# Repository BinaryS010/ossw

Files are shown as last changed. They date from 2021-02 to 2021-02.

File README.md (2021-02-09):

# Open SCART SWitch (OSSW)

## Overview

The **Open SCART Switch** (OSSW) is an RGB video and audio SCART switch designed to connect up to **8** RGB capable video game consoles with compatible display devices or scalers such as the **Open Source Scan Converter (OSSC).**

It was designed for use with properly constructed **RGB SCART** cables which correctly attenuate video and sync signals to levels safe for use with consumer grade televisions and the OSSC.

## Motivation

I designed this device to scratch a few itches, but mostly because there are currently no open source SCART switch designs within the retro gaming community.

It would have been cheaper to buy an existing solution, of which there are several very good ones, but I've learnt a lot throughout this project.

## Features

Currently the OSSW has the following features:

 * **8** SCART **inputs**, with **2** SCART **outputs**. Supports simultaneous output (**untested**).
 * Integrated **video amplifier** and switchable **sync stripper.**
 * Support for **Composite sync (CSYNC)**, **Sync-over-composite** or **Sync-on-Luma** on **SCART pin 20.**
 * Backlit LCD character **display** with menu driven interface.
 * Infrared **remote** and **5 button** control interface support.
 * Line-level **stereo audio** output via RCA jacks.
 * Built in 64Kb **EEPROM** to save and load configuration data.
 * Externally powered by **7.5V DC** supply. **2.5mm** barrel jack, centre positive.
 * Power **input polarity** and **over-voltage protection**, with onboard 1A fuse.
 * **SD Card** interface. (**unused/untested**, see future features).
 * Simple **expansion** interface for future feature support (**untested**).
 * Transient voltage **protection** for SCART Input and Outputs (**untested**).

### Limitations

The following are known limitations with the OSSW:

 * **Euro SCART** only. Currently NO support for **JP-21 SCART** standard.
 * Currently, **manual** switching only (see future features below).
 * No **audio amplification** is performed by the OSSW. Audio is currently split between the two SCART outputs and the RCA stereo jacks. A decrease in audio volume may be noticeable when using multiple outputs simultaneously (see future features below).
 * Input and output SCART ports can tolerate a maximum of **5V.** Use properly constructed RGB SCART cables to ensure no signal line (particularly, **SCART pin 8**) carries no more than **5V**.
 * Fimware only upgradeable using compatible programmer, such as an Atmel ICE (see future features).
 * Infrared remote control decoding is currently limited to **NEC protocol** only. Remote specific codes are hard-coded in the firmware.

### Future Features

The following features are planned for the OSSW:

 * Audio amplification.
 * Sync detection and automatic switching funtionality.
 * SD card based firmware upgrades and custom profile loading and saving.
 * Infrared remote control training and additional protocol decoding support.

### Warnings

Currently the device should only be used with **75 ohm** attenuated sync signals. Using the OSSW with **TTL** level sync signals will likely damage upstream devices such as the OSSC.

## Hardware

OSSW hardware overview and build instructions are located in the [HARDWARE](./HARDWARE.md) readme.

## Firmware

OSSW firmware build, programming and debugging instructions are located in the [FIRMWARE](./FIRMWARE.md) readme.

## Usage

OSSW usage instructions are located in the [USAGE](./USAGE.md) readme.

## Revision history

Please see the [CHANGELOG](./CHANGELOG)

## Disclaimer

This is a **DIY hobby** project currently in an early prototype stage. 

I am **not** a trained electrical engineer and although this device seems to work well with my equipment it may not work so well with other setups.

I **do not** intend to sell kits or completed devices. Design files are released to the community in the hope that the design may be improved upon should people wish to contribute. 

I **may** sell surplus PCBs at around cost price (+shipping) but **ONLY** if I have them available.

I offer **NO WARRANTY** of any kind and assume **NO RESPONSIBILITY** for potential damage or loss caused by this device. **Use the information in the repository at your own risk.**

I also offer **NO GUARANTEE** of support if you attempt to build and operate one of these devices. This is a hobby project and not a business. I'm open to contributions and suggestions on current or future features but it's unlikely I'll have time to answer direct queries.

## Donations

Donations are certainly not expected or required. However, if you would like to contribute a small donation towards future revisions of this project then please use one of the methods below:

 * Paypal: **ossw AT binarysolo.co.uk** (replace AT with @).
 * Bitcoin: **36CN15aT6YL5B6MN5kqg4JD5AhEYchCwxG**

Any and all donations are greatly appreciated.

## License

This project is licensed under the GNU General Public License, version 3 (GPLv3).

## Copyright

The **Open Scart Switch (OSSW)** project is Copyright(c) 2019-2021 Binary Solo.

Elements of the OSSW project that are derived from other works are credited within the relevant source files. Those works are copyright of their respective owners as indicated in the original copyright notice.

## Contact

The OSSW developer can be contacted via email as **ossw AT binarysolo.co.uk** (replace the AT with @).

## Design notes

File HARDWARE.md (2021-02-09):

# Hardware

This document is the main reference for the hardware components of the **OSSW** project intended to enable DIY build and assembly of the device.

The hardware is currently considered to be in an **ALPHA** release state. It may not be entirely safe for use across all setups and is subject to change. 

Certain elements of the hardware are sub-optimal, so please respect the fact that this is still considered a prototype design.

## Overview

The OSSW hardware forms the basis of an **8 input** and **2 output** RGB SCART switch with the following main components:

 * Dual PCB design consisting of:
    * Main board, 4 layers (~400mm x 130mm).
    * LCD display carrier board, 2 layers (~75mm x 28mm).
 * Laser cut acrylic case (3mm thickness). 

## Main components

The following components implement the major functionality of the OSSW:

 * Atmel/Microchip **ATSAMD21J18A** TQFP-64, microcontroller providing input/output and user interface control.
 * Information output via Midas **MCCOG22005A6W** 20x2 I2C LCD character display.
 * Bus switching via **SN74CBT3244** Octal FET bus switch ICs.
 * Video amplification via **THS7374** 4-channel SD video amplifier IC, including user selectable LPF filter.
 * Selectable video sync-stripping via **LM1881** sync separator IC.
 * Storage facilitated by **24LC64** 64Kb I2C EEPROM IC.
 * Infrared remote control via **TSOP 38238** 38kHz IR receiver/decoder module.
 * Manual control using 5 tactile buttons with hardware debouncing via **SN74HC14** Hex schmitt-trigger IC.
 * Serial wire debug support via 10 pin (2x5), 1.27mm pitch header.
 * SD-Card connector for future feature support and end-user firmware upgrade.
 * Bus status LED indicators (Green).

### Power supply

 * Power is delivered using a **7.5V DC (centre positive)** supply, with a current rating of **1A**.
 * The main power connector is a **FC681465P** 2.5mm barrel jack.
 * Power is regulated as follows:
    * 5V: **NCP1117ST503G**, 5V/1A LDO, powering bus switches and video amplifier.
    * 3V: **NCP1117ST333G**, 5V/1A LDO, powering ATSAMD MCU and additional low-voltage components.
 * Power status LED indicators (Red). 

## ATSAMD pinout

The following table describe the assigned pin functions of the OSSW's ATSAMD21J18A microcontroller.

|Port|Pin|Usage|Description|
|:---|---|:---|:---|
|PA00|1|XIN32|32.768kHz crystal|
|PA01|2|XOUT32|32.768kHz crystal|
|PA02|3|EXT_CTRL1|EXT control interface 1|
|PA03|4|EXT_CTRL2|EXT control interface 2|
|PA04|13|BUS_EN5|Bus Switch 5 enable|
|PA05|14|BUS_EN6|Bus Switch 6 enable|
|PA06|15|BUS_EN7|Bus Switch 7 enable|
|PA07|16|BUS_EN8|Bus Switch 8 enable|
|PA08|17|-|-|
|PA09|18|-|-|
|PA10|19|-|-|
|PA11|20|-|-|
|PA12|29|-|-|
|PA13|30|-|-|
|PA14|31|BYPASS|THS7374 LPF bypass enable/disable|
|PA15|32|SYNC_SPLIT|LM1881 Sync-stripper enable/disable|
|PA16|35|SERCOM1 PAD0|I2C SDA|
|PA17|36|SERCOM1 PAD1|I2C SCL|
|PA18|37|BTN_DOWN|Button Down|
|PA19|38|BTN_UP|Button Up|
|PA20|41|BTN_ACTION|Button Action|
|PA21|42|BTN_LEFT|Button Left|
|PA22|43|BTN_RIGHT|Button Right|
|PA23|44|-|-|
|PA24|45|-|-|
|PA25|46|-|-|
|PA27|51|IR_RECV|IR Receiver|
|PA28|53|-|-|
|PA30|57|SWCLK|-|
|PA31|58|SWDIO|-|
|PB00|61|SD_CS|SPI/SD-Card Chip Select|
|PB01|62|SD_MISO|SPI/SD-Card Master-In, Slave-Out|
|PB02|63|-|-|
|PB03|64|-|-|
|PB04|5|EXT_CTRL3|EXT control interface 3|
|PB05|6|EXT_CTRL4|EXT control interface 4|
|PB06|9|BUS_EN1|Bus Switch 1 enable|
|PB07|10|BUS_EN2|Bus Switch 2 enable|
|PB08|11|BUS_EN3|Bus Switch 3 enable|
|PB09|12|BUS_EN4|Bus Switch 4 enable|
|PB10|23|-|-|
|PB11|24|-|-|
|PB12|25|-|-|
|PB13|26|-|-|
|PB14|27|-|-|
|PB15|28|-|-|
|PB16|39|-|-|
|PB17|40|-|-|
|PB22|49|-|-|
|PB23|50|LCD_BL|LCD LED Backlight enable/disable|
|PB30|59|SD_MOSI|SPI/SD-Card Master-Out, Slave-In|
|PB31|60|SD_SCK|SPI/SD-Card Clock|
|RESET|52|RESET|Button Reset|

## Manufacture

Building the OSSW device from scratch is a relatively difficult task due to the high part count and the size of some of the components used. 

However, it should be achievable by most experienced electronics hobbyists comfortable with soldering at least **0402/0603 SMD** components and **0.5mm pin pitch** surface mount IC packages. 

Hot air rework stations and/or reflow ovens will certainly help although are not strictly required. The prototype unit was built using a **temperature controlled** KSGER T12 soldering iron and a variety of tips suitable for general purpose and SMD work.

### PCBs

The PCBs for DIY OSSW builds can be ordered from any low cost PCB house and have few special requirements. Prototype units were manufactured by JLCPCB and are of acceptable quality.

Due to the size of the main board and the 4 layer design, manufacture and shipping costs are slightly higher. For reference, 5 copies of both boards for the prototype cost around **£80** total (including import taxes and shipping).

GERBER files for the two PCBs can be found in the *GERBER/* folder for the relevant board and version under the *pcb/* folder in the root of the repository.

#### Design files

The OSSW PCB hardware was designed using the **KiCAD** EDA Suite, version **5.1.6-c6e7f7d~87~ubuntu18.04.1, release build** at the time of writing. Full design files are available in the *pcb/* folder within the source repository.

There is currently no intention to port the design to other EDA suites.

#### Ordering

 * Main OSSW board:
    * Thickness: **2.0mm** (1.6mm is really too thin for a board of this size).
    * Surface finish: No special requirement, HASL is fine.
    * Solder mask: Your choice, **Black** looks good but is **HARDER** to work and clean after soldering.

 * LCD carrier board:
    * Thickness: **1.6mm.**
    * Surface finish and solder mask: No special requirements.

#### Bill of Materials

The BOMs for each OSSW PCB can be found in the *BOM/* folder under the relevant board revision within the *pcb/* folder in the root of the source repository. 

As the BOM will likely change across board revisions it is best to place it alongside the relevant design files.

Generally, all schematic elements within the design contain the manufacturer part number and relevant datasheet links. 

Large online electronics distributors (Mouser/Digikey/Farnell etc) carry most of the BOM items. The exception here is the SCART connectors which are either salvaged or available from online auction sites such as Ebay.

The BOM for the two PCBs is generated by the **InteractiveHtmlBom** plugin for KiCAD.

### Assembly

Component placement should be self-explanatory from the included design files for each board and revision. Use of the **InteractiveHtmlBOM** plugin for KiCAD can be useful during soldering.

Based on hand assembly of the prototype unit, the following tips and warnings may prove useful.

#### LCD carrier board

When assembling the LCD daughter board for use with the OSSW, please ensure you **omit** the parts labelled **R1** and **R2.** These footprints are used as pull-up resistors for the **I2C** bus. Since the main OSSW PCB contains these parts they are **not** required on the LCD display carrier board.

**Note:** Failure to adhere to this warning will cause communication errors on the I2C bus and the OSSW is unlikely to boot correctly.

#### Tips

 * Flux, preferably the liquid no-clean variety, is required to ensure surface mount components are soldered easily and correctly.
 * Residual flux from soldering should be cleaned using >90% Isopropyl Alcohol (IPA) and a soft anti-static brush.
 * It is advised to start by soldering the ATSAMD microcontroller and verifying there are no shorted pins before soldering the rest of the components.
 * For the remainder of the components, start with the lowest profile components and continue in that fashion for the rest of the build.
 * Solder all connectors and buttons last. It is advisable to test the unit before soldering ALL the SCART connectors onto the board.
 * Once the unit is verified to be working, the LCD daughter board can be permanently fixed in place using the solder pads on both sides of the main board.
 * Use a **multimeter** to verify connectivty, particularly with the power circuitry, **BEFORE** powering on a newly assembled unit.

#### Warnings

 * **DO NOT** use hot air to solder, or nearby to, **ANY** plastic containing components on the board. Doing so will likely melt the plastic and damage/destroy the component. Kapton tape can be used to carefully isolate already soldered plastic components if rework is required. 
 * Ensure **all** safety precautions are taken when soldering components. Solder fumes and flux are generally considered to be **toxic** substances. 
 * If using leaded solder, this device will not be RoHS compliant. Prototype units were assembled using leaded solder.

### Case

A **preliminary** design for a two part case, consisting of a top and bottom plate, is included within this repository. **As I have not made one yet, I cannot guarantee it is correct.**

It is expected that the case can be laser cut or machined from 3mm acrylic using a variety of online merchants, or at home if you have the equipment.

It may be possible to 3D print the case design, subject to access to a printer with a build volume of ~400mm x 150mm. This is likely to be of a lower quality than the acrylic option.

### Design files

The OSSW case was designed using **Inkscape**, version **0.92.3 (2405546, 2018-03-11)** at the time of writing. Files are available in the *case/* folder within the source repository for the relevant main board revision.

### Additional components

As well as the electronic components, you will also need the following components to completely assemble the OSSW:

 * Brass/Steel PCB standoffs, 12mm (**6** x Male/Female, **26** x Female/Female).
 * M3 x 6mm screws (**26**).

### Future Work

There are plenty of features that *could* be implemented into the hardware, subject to demand. These features are already outlined in the main [README](./README.md) file for this project.

I am aware that the current BOM is rather costly and could do with some consolidation.

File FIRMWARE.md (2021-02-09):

# Firmware

This document is the main reference for the firmware components of the OSSW project intended to enable development, debugging and programming of the Atmel ATSAMD microcontroller.

The software is currently considered to be in an **ALPHA** release state. Generally, all of the existing features have been tested and appear stable under a reasonable amount of usage to date.

## Development environment

The OSSW firmware has been developed using almost exclusively open source environments and toolchains. The primary development environment is **Ubuntu 18.04.4 LTS x86_64.** 

It should be relatively easy to use other Linux based development environments.

### Prequisite packages

In order to build the firmware and program the OSSW, the development environment must first be configured.

### Build tools

Firstly, install the required build packages using the package manager of your preferred distribution.

```
sudo apt-get install build-essential openocd telnet
```

### ARM GNU toolchain

Developing for the ATSAMD microcontroller requires a cross toolchain for the ARM Cortex M0+ architecture. 

Whilst you are free to build or use one you may already have, I chose to use the **official** GNU ARM Embedded toolchain which can be downloaded from this [link](https://developer.arm.com/tools-and-software/open-source-software/developer-tools/gnu-toolchain/gnu-rm/downloads)

The version used during development of the OSSW was: [Version 7-2017-Q4-major](https://developer.arm.com/-/media/Files/downloads/gnu-rm/7-2017q4/gcc-arm-none-eabi-7-2017-q4-major-linux.tar.bz2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,64-bit,,Linux,7-2017-q4-major).

Later versions have **NOT** been tested, but I expect they'll work just fine.

#### Download and extract toolchain

Download the toolchain and extract it to a location of your choosing. In my case I use `~/toolchains` as follows:

```
mkdir ~/toolchains
cd ~/toolchains

wget "https://developer.arm.com/-/media/Files/downloads/gnu-rm/7-2017q4/gcc-arm-none-eabi-7-2017-q4-major-linux.tar.bz2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,64-bit,,Linux,7-2017-q4-major" -O gcc-arm-none-eabi-7-2017-q4-major.tar.bz2

tar xjvf gcc-arm-none-eabi-7-2017-q4-major.tar.bz2
ln -s gcc-arm-none-eabi-7-2017-q4-major/install-native arm-none-eabi
```

#### Configure PATH environment variable

Once extracted, you now need to add the toolchain to your `PATH` environment variable for the makefile to pick it up and cross compile the firmware. In order to do this, you could add the following lines to your `~/.profile` as follows:

```
PATH="$PATH:$HOME/toolchain/arm-none-eabi/bin/"
export PATH
```

Once this is complete, `source` your profile to pick up the changes and add the toolchain to your path.

```
. ~/.profile
```

Toolchain configuration is now complete.

### Atmel/Microchip ASF

In order to aid development, and possibly portability to alternative ATSAMD devices, the OSSW firmware was developed against the Atmel/Mircochip ASF development kit. 

**Note:** The only portions of the ASF that are really used are the ATSAMD starup code and memory mapped register definitions and helper macros. The OSSW firmware does **NOT** use the full Hardware Abstraction Layer (HAL) library features provided by the ASF so the included code is only very minimal, probably around 1KB.

Follow the steps below to download and configure the ASF:

#### Download ASF

Download the standalone ASF archive from [here](https://www.microchip.com/en-us/development-tools-tools-and-software/libraries-code-examples-and-more/advanced-software-framework-for-sam-devices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). 

The version used to develop the OSSW firmware was **3.47.0.96** although the current version available for download is **3.49.1.105** at the time of writing. It is a **~0.5Gb** download.

#### Extract ASF

Firstly, extract the ASF to a location **outside** of the OSSW source repository. In this example *~/share* is used.

```
cd ~
mkdir share
cd share
unzip ~/Downloads/asf-standalone-archive-<version>.zip
ln -s xdk-ask-<version> xdk-asf
```

#### Link to ASF

Now that the ASF is installed to a known location, the *Makefile* needs to be able to locate the relevant files needed to build the firmware.

The creation of an additional directory is required in the root of the OSSW source respository to point to the external files. In this example, an *ext/* directory is created.

```
cd <ossw_repository_directory>
mkdir ext
cd ext
```

Now create the following symlinks to the various ASF components required, replacing `username` with your own:

```
ln -s /home/<username>/share/xdk-asf/thirdparty/CMSIS/Include/ cmsis
ln -s /home/<username>/share/xdk-asf/thirdparty/CMSIS/Include/ include
ln -s /home/<username>/share/xdk-asf/sam0/utils/linker_scripts/samd21/gcc/samd21j18a_flash.ld samd21j18a_flash.ld
ln -s /home/<username>/share/xdk-asf/sam0/utils/cmsis/samd21/source/gcc/startup_samd21.c startup_samd21.c
ln -s /home/<username>/share/xdk-asf/sam0/utils/cmsis/samd21/source/system_samd21.c system_samd21.c
ln -s /home/<username>/share/xdk-asf/sam0/utils/cmsis/samd21/source/system_samd21.h system_samd21.h
```

Setup of the development environment is now complete.

#### Additional reference

A good reference for bare-metal ARM programming can be found on the MickMake YouTube channel [here](https://youtu.be/xy62eC6bd44). The instructions in this guide are based on this video.

### Additional tools

#### Programmer (required)

This document assumes you have an Atmel ICE or other suitable programmer available and  connected to the onboard *Serial Wire Debug* port located on the main OSSW board. For now, this is the **ONLY** method available for programming and/or debugging the Atmel ATSAMD microcontroller on the OSSW.

If using an Atmel ICE, the **SAM** debug port should be used as opposed to the **AVR** port on the programmer.

#### Logic Analyser (optional)

A logic analyser is often useful for both debugging and verifying commnication signals during development, particularly the protocols involved in I2C, SPI and Infrared communicatons. 

It is however optional, and not required to build and program an OSSW device.

## Configure programmer

The OSSW repository contains an **openocd** configuration file in the *cfg/* directory in the root of the source repository.

In order to configure your programmer correctly you need update the configuration file with the appropriate USB VID, PID and serial number of your particular programmer.

These values can be obtained by the following commands with the programmer connected and powered on:

```
lsusb -v | less 
```

Search the output for the following lines:

```
idVendor           0x03eb Atmel Corp.
idProduct          0x2141 ICE debugger
bcdDevice            1.01
iManufacturer           1 Atmel Corp.
iProduct                2 Atmel-ICE CMSIS-DAP
iSerial                 3 J47201015054
```

The relevant values from *your* output fields **idVendor** (in this case 0x03eb), **idProduct** (0x2141) and **idSerial** (J47201015054) should be entered into the *cfg/openocd.cfg* file before attempting to program or debug the firmware.

## Debugging the firmware

Being able to debug the Atmel ATSAMD21J18A microcontroller is essential during development and testing. The included *Makefile* has a few targets to enable this. 

Firstly, to ensure relevant debugging information is present within the firmware binary, a **debug** target is also provided within the *Makefile*.

Secondly, the **openocd**  target connects to the ATSAMD and places it under the control of the openocd debugger. An openocd config file suitable for the ATSAMD21J18A target is present within the *cfg/* directory in the root of the source repository.

Finally, the **gdb** target initiates a debug session using GDB to enable the developer to test and debug the firmware.

To initiate a debug session running, follow the steps outlined below. All shell commands should be executed from the *root* of the source repository,  where the *Makefile* resides. 

The following instructions assume you have our Atmel ICE programmer connected to the OSSW using the **SAM** port (not the **AVR** port) on the programmer.

### Build a debug firmware

In one shell:

```
make debug
```

### Connect to the ATSAMD target

In a second shell:

```
make openocd
```

### Initiate a GDB session

In a third shell:

```
make gdb
```

Once the GDB session is established, run the following commands to load the debug firmware:

```
load
break main
monitor reset init
```

The session is now configured for debugging, for example:

`break <breakpoint>` or `c` to resume execution.

## Flashing the firmware

Currently the only method of permanently flashing the firmware of the OSSW is via **openocd** using an Atmel ICE or other suitable programmer capable of interfacing with the **Serial Wire Debug** port present on the main OSSW board. 

As with the debugging steps above, the following instructions assume you have our Atmel ICE programmer connected using the **SAM** port (not the **AVR** port).

The included *Makefile* includes a few targets to make permanently flashing the firmware a little easier.

Firstly, release mode firmware should not include debugging information or symbols to ensure appropriate operation and smaller firmware binaries. The default **make** target will build a release mode firmware image.

Secondly, the **openocd**  target connects to the ATSAMD and places it under the control of the openocd debugger.

To flash the firmware, follow the steps outlined below. All shell commands should be executed from the *root* of the source repository, where the *Makefile* resides. 

### Build release firmware

In one shell:

```
make
```

### Connect to the ATSAMD target

In a second shell:

```
make openocd
```

### Initiate an OpenOCD session

In a third shell:

```
telnet localhost 4444
```

### Flash the firmware

In the OpenOCD session, enter the following commands:

```
reset halt
flash list
flash banks
flash probe 0
flash write_image erase ossw.bin 0x00000000
exit
```

### Enable flash read protection (optional)

This step is not required, as the firmware is open source anyway, but probably a good habit to get into.

TODO

Once this step has been performed, the flash will be protected and cannot be read via an external programmer.

## Remove firmware build artefacts

Artefacts generated by the build process can be removed by running `make clean` in the *root* of the source repository, where the *Makefile* resides.

**Note:** Running the above command will remove all artefacts, including built firmware binaries.

## Infrared remote control support

Currently, the IR support within the firmware is limited to a simple 5 button remote I had lying around from an old LED strip light. The IR codes specific to that remote control are currently hardcoded into the firmware.

In order to use the IR functions of the OSSW, you will need to perform the following steps:

 * Obtain a remote control known to use the NEC Infrared remote control protocol.
 * Obtain a method for recording and displaying the remote control codes emitted by your particular device. An Arduino for instance and the IR protocol library could be used.
 * Modify the global structure `g_nec_keymap` in the source file *src/ossw_ir_nec.c*, changing the values to the ones you have captured.
 * Save the changes, rebuild the firmware, flash the device and test the new codes.

Another option would be to train a universal remote control or mobile phone to send the codes already in the firmware.

Additional protocol support and remote training functionality are on the roadmap for integration into the OSSW firmware at some point in the future.

## Version history

#### Version 1.1 [ALPHA]
Initial prototype. First release.

#### Version 1.0
Internal prototype. Not released.

## License

This firmware is licensed under the GNU General Public License, version 3 (GPLv3).

## Credits

The OSSW project has used concepts and/or code from the projects outlined below. Every attempt has been made to respect the copyright of the originators and preserve the original licensing conditions:

 * **Open Source Scan Converter (OSSC)**: LCD menu code, concepts and supporting macros adapted for use within this project. ([Github](https://github.com/marqs85/ossc))
 * **Arduino-IRremote**: Portions of the IR receive and NEC protocol decoding logic plus supporting macros adapted for use within this project. ([Github](https://github.com/Arduino-IRremote/Arduino-IRremote))

## Copyright

The **Open Scart Switch (OSSW)** project is Copyright(c) 2019-2021 Binary Solo.

The **Advanced Software Framework (ASF)** is Copyright(c) Microchip Corporation.

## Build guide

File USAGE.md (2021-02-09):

# USAGE

This document provides operating instructions for the **OSSW** device.

## RGB SCART Cables

The OSSW can only tolerate a maximum of **5V** on any of it's SCART input and output ports. As such it is **highly** recommended to use only good quality, dedicated RGB SCART cables, made specifically for retro gaming consoles.

The OSSW is known to work well with cables wired for **Composite Sync (CSYNC), Sync-over-composite** and **Sync-on-Luma** on **SCART Pin 20.** 

Care should be taken to ensure that voltage on **ANY** SCART pin, particularly the **AV switching pin 8,** does not exceed **5V.**

The following cables have been tested for use with the OSSW connected onwards to an **Open Source Scan Converter** and appear to work well:

 * **Sega Master System 1:** 
    * Sega Master System 1 / Mega Drive 1 RGB SCART PACKAPUNCH PRO CABLE - CSYNC - [UK seller](https://www.retrogamingcables.co.uk/sega/master-system-model-1/SEGA-MASTER-SYSTEM-1-RGB-SCART-CABLE-PACKAPUNCH-PRO)
 * **Sega Megadrive 2:** 
    * Sega Mega Drive 2 / Genesis 2 RGB SCART PACKAPUNCH PRO CABLE - CSYNC - [UK seller](https://www.retrogamingcables.co.uk/sega/mega-drive-2/sega-mega-drive-2-sega-genesis-2-rgb-av-scart-cable-tv-lead)
 * **Sega Saturn:** 
    * Sega Saturn RGB SCART PACKAPUNCH PRO CABLE - SYNC ON LUMA - [UK seller](https://www.retrogamingcables.co.uk/sega/saturn/SEGA-SATURN-RGB-SCART-PACKAPUNCH-PRO-CABLE)
 * **Nintendo SNES:** 
    * Super Nintendo PAL SNES RGB SCART PACKAPUNCH PRO CABLE - CSYNC w/STRIPPER - [UK seller](https://www.retrogamingcables.co.uk/SUPER-NINTENDO-SUPER-FAMICOM-GAMECUBE-WII-N64-SNES-NES-RGB-SCART-CSYNC-COMPONENT-YPBPR-HDTV-HDMI-VIDEO-CABLES-CORDS-RAD2X/SUPER-N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)
 * **Nintendo Gamecube:**
    * Nintendo GameCube GC RGB SCART cable (PAL) PACKAPUNCH PRO - CSYNC w/STRIPPER - [UK seller](https://www.retrogamingcables.co.uk/SUPER-NINTENDO-SUPER-FAMICOM-GAMECUBE-WII-N64-SNES-NES-RGB-SCART-CSYNC-COMPONENT-YPBPR-HDTV-HDMI-VIDEO-CABLES-CORDS-RAD2X/PAL-GAM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)

## Powering the OSSW

Please follow the instructions laid out here in order to correctly power up the OSSW SCART switch.

### Power supply

 * The OSSW is powered by a **7.5V DC, 1 Amp, centre-positive** supply. A good quality variable voltage AC to DC power supply is ideal for powering the device.
 * The power supply tip should be compatible with the **2.5mm** DC barrel jack present at the rear of the main board. It should not be loose in the power receptacle.
 * Although there is **polarity protection** built into the OSSW, care should still be taken to correctly connect the power supply.

### Connecting the device

 * Ensure the AC outlet is switched **OFF** at the wall.
 * Ensure the power switch on the OSSW is in the **OFF** position (angled towards the **FRONT** of the board).
 * Connect the adapter to the AC outlet and the tip of the DC supply to the barrel jack on the rear of the OSSW.
 * Connect SCART cables to consoles and upstream devices (TVs, scalers etc). **It is important to do this with the power OFF!**
 * Switch the AC outlet **ON** at the wall.
 * Turn on any other AV equipment in your setup.
 * Finally, turn **ON** the OSSW by pushing the toggle switch towards the **REAR** of the device.

The OSSW should now power up, briefly displaying a splash screen. After approximately 5 seconds the main interface will be displayed and the OSSW is ready for use.

## Operating the OSSW

The following section outlines the options for controlling the OSSW, using either the button interface present on the device or infrared remote control. 

It also provides details on the information presented on the LCD display and how to navigate the menu system.

### Controls

#### Button controls

The following tactile button control interfaces can be used with the OSSW:

##### Navigation buttons

The OSSW main board contains 5 tactile push buttons arranged in a directional pad style, '+' configuration. The buttons function as follows:

|Button position|Label|Usage - **Information view** | Usage - **Menu view**|
|:---:|:---:|:---:|:---:|
|Top|UP|-|Move cursor up|
|Centre|ACTION|Enter menu|Select current menu item|
|Bottom|DOWN|-|Move cursor down|
|Left|LEFT|Select **previous** SCART input|Decrease value OR Toggle item On/Off|
|Right|RIGHT|Select **next** SCART input|Increase value OR Toggle item On/Off|

##### Reset button

The **RESET** button, located to the left of the LCD display panel at the front of the unit, resets the device.

#### Infrared remote control

The OSSW also includes limited support for an Infrared remote control interface. 

As with the tactile button interface, 5 buttons on the remote control are used, and when used in a similar directional layout to the tactile buttons their functions are **identical.**

### Display

The LCD display on the OSSW provides information output to the user and facilitates navigation of the menu system in order to configure the device according to the user's requirements.

The LCD display has three main modes as follows:

#### Startup

The startup screen is shown briefly after the device is powered up. It simply displays the **device name** and current **firmware version.** 

After **5 seconds** the OSSW switches to display the main information screen (see below).

No user control is possible whilst the OSSW is displaying the startup screen.

#### Information screen

The information screen is the primary display mode for the OSSW. It conveys several pieces of information to the user:

 * **First line:** The **label** assigned to the currently selected input.
    * By default these are set to be **Input 1, Input 2** etc.
    * Each input label can be changed within the menu system to one of a predefined set of system names contained within the firmware, i.e. **Sega Megadrive, Sega Saturn** etc.
    * Assigned input labels can be saved to the internal EEPROM of the OSSW and are restored when the system is next powered on.

 * **Second line:** The currently selected **SCART** input number plus sync stripper and low pass filter enabled/disabled indicators.
    * A left arrow icon (**<**) points towards the currently selected SCART input. 
    * To the right of the second line on the display are two indicators. A small '**S**' indicates the enabled/disabled state of the **sync-stripper.** A small '**L**' indicates the enabled/disabled state of the video amplifier's **low pass filter.**
    * Those functions are **enabled** when the indicators have a **dark background.**

In order to select the desired SCART input, simply use the **LEFT** and **RIGHT** buttons. The menu can be acesssed using the **ACTION** button (see menu section below). 

#### Menu

The OSSW includes a menu system for configuring the device settings according to the needs of the user. The menu is organised in a tree structure to group related configuration items together and provide a consistent navigation experience.

This structure is as follows:

||||
|---|---|---|
|General options: |||
| |Save settings ||
| |Load settings ||
| |Default settings ||
|Input options: |||
| |Default input ||
| |Input labels:||
| | |Input 1|
| | |  ...  |
| | |Input 8|  
| |Sync strip ||
|Output options: |||
| |Low pass filter| |
|Display options:
| |Menu timeout ||
| |LCD constrast ||
| |LCD backlight
|About |||
| | | |

The menu is controlled as follows:

 * Menu levels and items are selected using the **ACTION** button. 
 * Options that present a value that can be changed are selected using the **LEFT** or **RIGHT** buttons. 
 * Menu screens are scrolled using the **UP** and **DOWN** buttons.

Each menu level includes either a **previous menu** or an **exit menu** option to aid navigation.

The menu includes a timeout, meaning the display will automatically revert to the main information screen if no button is pressed for the configured length of time. By default the menu timeout is **5 seconds** although this can be changed and saved according to the user's preference.

Settings can be saved and loaded by using the **Save settings** and **Load settings** respectively in the *General options* menu. **Settings are NOT automatically saved by the system.**

#### LCD backlight

The OSSW LCD display includes a user configurable LED backlight. 

By default, the backlight is configured to be always **ON.** However, by using the menu system as described above, the backlight can be configured to turn **OFF** after a pre-determined delay between **1** and **60** seconds.

Setting the backlight timeout to **0** in the menu will cause the backlight to remain **ON** whilst the device is powered.

### SD card interface

The OSSW device has a micro SD-card slot at the front of the unit. This is **unused** with the current firmware, but is included to support future features.

### Expansion connector

The OSSW device has a 14-pin expansion connector, labelled **EXT,** on the left side of the unit. This is **unused** with the current firmware, but is included to support future expansion functionality.

## Warnings

 * Using power supplies outside the specifications outlined above may **damage or destroy** the OSSW.
 * Ensure power is **OFF** to all equipment in your setup **BEFORE** connecting or disconnecting SCART/audio or power cables. **Failure to adhere to this rule could damage parts of your setup, including the OSSW.**

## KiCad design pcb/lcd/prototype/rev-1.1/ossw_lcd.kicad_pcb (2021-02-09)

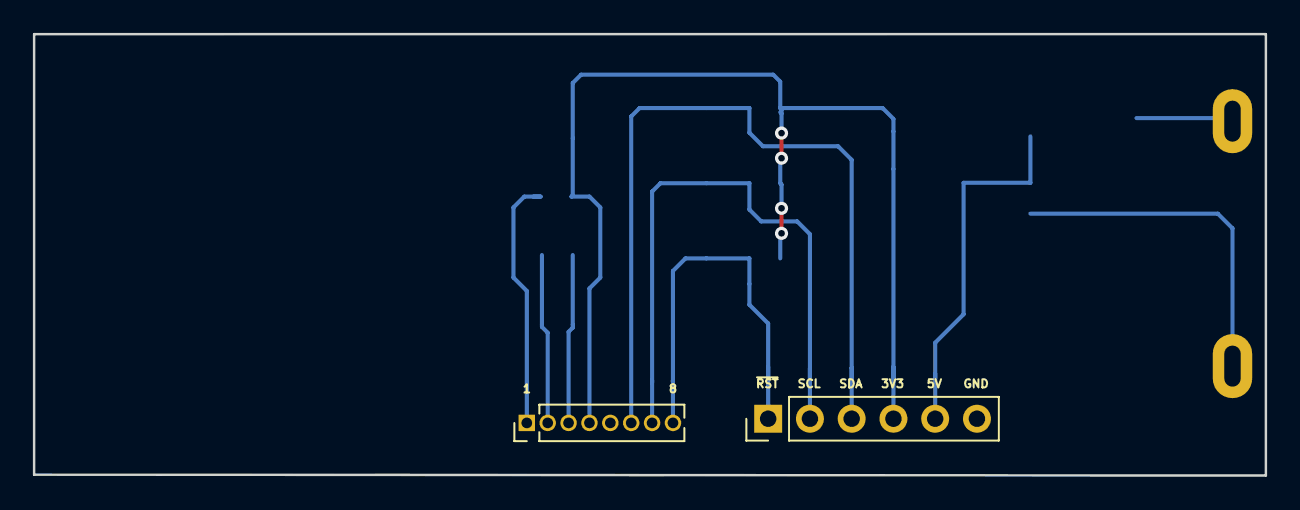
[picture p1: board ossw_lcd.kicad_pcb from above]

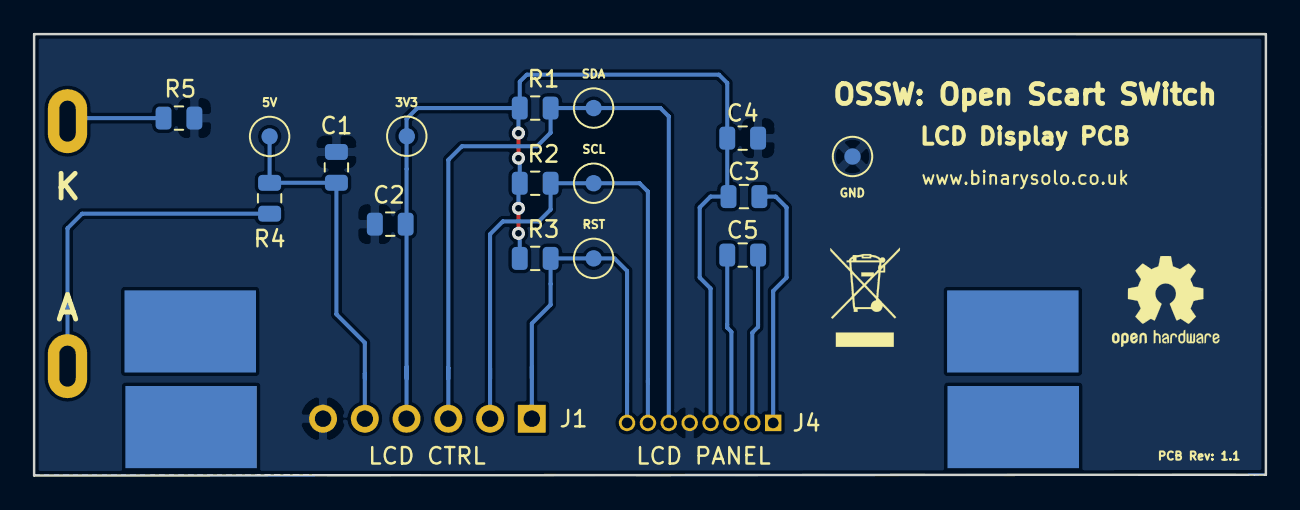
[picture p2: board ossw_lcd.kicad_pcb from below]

Board: 2 copper layers, 74.9 x 26.8 mm, 23 parts (21 on the bottom side), 11 nets.

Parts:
3V3, 5V: TestPoint; TestPoint_Pad_D2.0mm
C1, C2, C3, C4, C5: 1uF; C_0805_2012Metric
GND: TestPoint; TestPoint_Pad_D2.0mm
J1: LCD CTRL; PinHeader_1x06_P2.54mm_Vertical
J2: LCD BL; lcd_backlight
J3: ANCHOR 1; anchor
J4: LCD PANEL; PinHeader_1x08_P1.27mm_Vertical
J5: ANCHOR 2; anchor
J6: ANCHOR 3; anchor
J7: ANCHOR 4; anchor
R1, R2, R3: 4K7; R_0805_2012Metric
R4: 47R; R_0805_2012Metric
R5: 0R; R_0805_2012Metric
RST: TestPoint; TestPoint_Pad_D2.0mm
SCL: TestPoint; TestPoint_Pad_D2.0mm
SDA: TestPoint; TestPoint_Pad_D2.0mm

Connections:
3V3: 3V3.1, C2.1, C3.2, C4.1, J1.4, J4.4, R1.2, R2.2, R3.2
5V: 5V.1, C1.1, J1.5, R4.2
GND: C1.2, C2.2, C4.2, GND.1, J1.6, J4.5, R5.2
unnamed: C3.1, J4.1
unnamed: C5.1, J4.2
unnamed: C5.2, J4.3
unnamed: J2.1, R4.1
unnamed: J2.2, R5.1
RST: J1.1, J4.8, R3.1, RST.1
SCL: J1.2, J4.7, R2.1, SCL.1
SDA: J1.3, J4.6, R1.1, SDA.1

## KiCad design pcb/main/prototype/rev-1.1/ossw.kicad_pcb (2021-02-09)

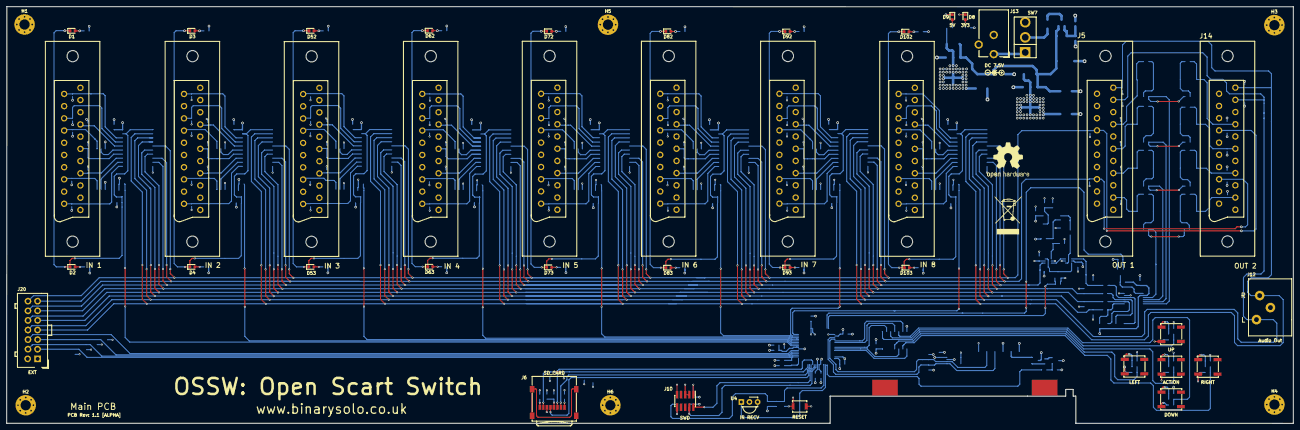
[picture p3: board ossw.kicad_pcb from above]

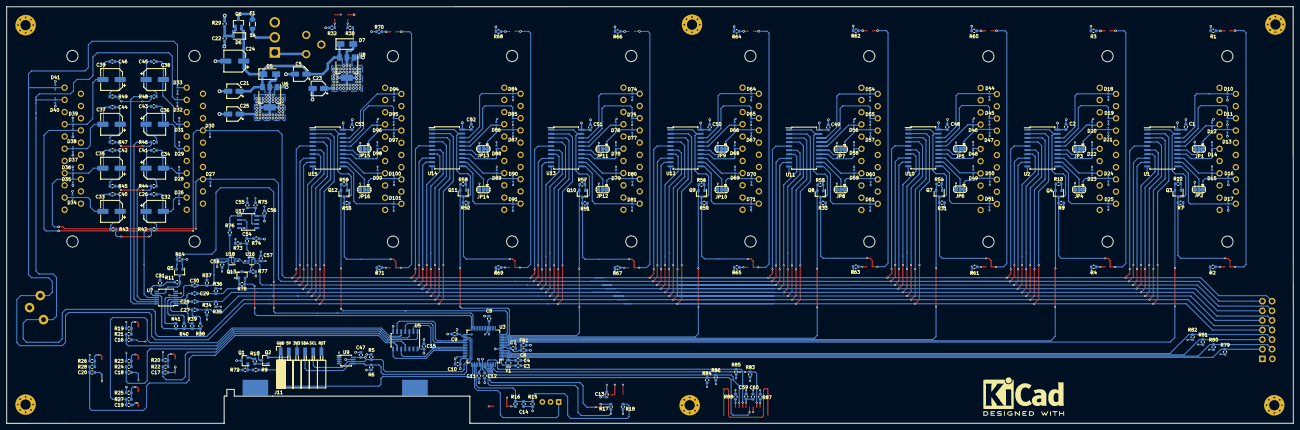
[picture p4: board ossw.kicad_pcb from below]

Board: 4 copper layers, 401.5 x 130.1 mm, 332 parts (283 on the bottom side), 207 nets.

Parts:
C1, C2, C7, C8, C9, C10, C12, C13, C15, C16, C17, C18, C19, C20, C26, C31, C40, C41, C42, C43, C44, C45, C46, C47, C48, C49, C50, C51, C52, C53, C56, C57, C58, C59: 0.1uF; C_0603_1608Metric
C3, C4: 6.4pF; C_0603_1608Metric
C5, C21, C23, C25: 10uF; CP_Elec_4x5.4
C6, C60: 10uF; C_0603_1608Metric
C11: 1uF; C_0603_1608Metric
C14: 100pF; C_0603_1608Metric
C22: 15nF/50V; C_0603_1608Metric
C24: 47uF; CP_Elec_6.3x5.4
C27, C28, C29, C30, C54, C55: 100nF; C_0603_1608Metric
C32, C33, C34, C35, C36, C37, C38, C39: 220uF; CP_Elec_6.3x7.7
D1, D2, D3, D4, D52, D53, D62, D63, D72, D73, D82, D83, D92, D93, D102, D103: LED_Small; LED_0603_1608Metric
D5, D7: 1N4002; D_SMA
D6: 10V; D_SOD-123
D8: 3V3; LED_0603_1608Metric
D9: 5V; LED_0603_1608Metric
D10, D11, D12, D13, D14, D15, D16, D17, D18, D19, D20, D21, D22, D23, D24, D25, D26, D27, D28, D29, D30, D31, D32, D33, D34, D35, D36, D37, D38, D39, D40, D41, D44, D45, D46, D47, D48, D49, D50, D51, D54, D55, D56, D57, D58, D59, D60, D61, D64, D65, D66, D67, D68, D69, D70, D71, D74, D75, D76, D77, D78, D79, D80, D81, D84, D85, D86, D87, D88, D89, D90, D91, D94, D95, D96, D97, D98, D99, D100, D101: D_TVS; D_0402_1005Metric
F1: 1A; Fuse_1206_3216Metric
FB1: BLM21PG331SN1; L_0603_1608Metric
H1, H2, H3, H4, H5, H6: MountingHole; MountingHole_3.2mm_M3_Pad_Via
J1: IN 1; SCART_Female
J2: IN 3; SCART_Female
J3: IN 2; SCART_Female
J4: IN 4; SCART_Female
J5: OUT 1; SCART_Female
J6: SD_CARD; microSD_HC_Wuerth_693072010801
J7: IN 5; SCART_Female
J8: IN 6; SCART_Female
J9: IN 7; SCART_Female
J10: SWD; PinHeader_2x05_P1.27mm_Vertical_SMD
J11: LCD; Socket_Strip_Angled_1x06_Pitch2.54mm
J12: Audio Out; PSG01550
J13: DC 7.5V; BarrelJack_FC681465P
J14: OUT 2; SCART_Female
J15: IN 8; SCART_Female
J16: A1; anchor
J17: A2; anchor
J18: A3; anchor
J19: A4; anchor
J20: EXT; TE_MATE-N-LOK_4-794630-4_2x07_P3.0mm_Vertical
JP1: FUNC1; SolderJumper-3_P1.3mm_Bridged12_RoundedPad1.0x1.5mm
JP2: BLANK1; SolderJumper-3_P1.3mm_Bridged12_RoundedPad1.0x1.5mm
JP3: FUNC2; SolderJumper-3_P1.3mm_Bridged12_RoundedPad1.0x1.5mm
JP4: BLANK2; SolderJumper-3_P1.3mm_Bridged12_RoundedPad1.0x1.5mm
JP5: FUNC3; SolderJumper-3_P1.3mm_Bridged12_RoundedPad1.0x1.5mm
JP6: BLANK3; SolderJumper-3_P1.3mm_Bridged12_RoundedPad1.0x1.5mm
JP7: FUNC4; SolderJumper-3_P1.3mm_Bridged12_RoundedPad1.0x1.5mm
JP8: BLANK4; SolderJumper-3_P1.3mm_Bridged12_RoundedPad1.0x1.5mm
JP9: FUNC5; SolderJumper-3_P1.3mm_Bridged12_RoundedPad1.0x1.5mm
JP10: BLANK5; SolderJumper-3_P1.3mm_Bridged12_RoundedPad1.0x1.5mm
JP11: FUNC6; SolderJumper-3_P1.3mm_Bridged12_RoundedPad1.0x1.5mm
JP12: BLANK6; SolderJumper-3_P1.3mm_Bridged12_RoundedPad1.0x1.5mm
JP13: FUNC7; SolderJumper-3_P1.3mm_Bridged12_RoundedPad1.0x1.5mm
JP14: BLANK7; SolderJumper-3_P1.3mm_Bridged12_RoundedPad1.0x1.5mm
JP15: FUNC8; SolderJumper-3_P1.3mm_Bridged12_RoundedPad1.0x1.5mm
JP16: BLANK8; SolderJumper-3_P1.3mm_Bridged12_RoundedPad1.0x1.5mm
Q1: BC847; SOT-23
Q2: BC857; SOT-23
Q3, Q4, Q5, Q7, Q8, Q9, Q10, Q11, Q12, Q13: BSS138; SOT-23
Q6: SI2399; SOT-23
R1, R2, R3, R4, R60, R61, R62, R63, R64, R65, R66, R67, R68, R69, R70, R71: 220R; R_0603_1608Metric
R5, R6: 4K7; R_0603_1608Metric
R7, R8, R11, R12, R13, R14, R19, R20, R21, R22, R23, R24, R25, R26, R27, R28, R31, R33, R50, R51, R52, R53, R54, R55, R56, R57, R58, R59, R72, R77, R78, R83, R84, R85, R86, R87, R88: 10K; R_0603_1608Metric
R9, R10, R17: 1K; R_0603_1608Metric
R15, R79, R80, R81, R82: 2K2; R_0603_1608Metric
R16: 330R; R_0603_1608Metric
R18: 39R; R_0603_1608Metric
R29: 12K; R_0603_1608Metric
R30: 150R; R_0603_1608Metric
R32, R34, R35, R36, R37, R42, R43, R44, R45, R46, R47, R48, R49, R73: 75R; R_0603_1608Metric
R38, R39, R40, R41, R74: 5.6M; R_0603_1608Metric
R75: 680K; R_0603_1608Metric
R76: 470R; R_0603_1608Metric
SW1: RESET; MPTFP2-Q-TR
SW2: UP; LTL-613R-V-TR
SW3: LEFT; LTL-613R-V-TR
SW4: ACTION; LTL-613R-V-TR
SW5: DOWN; LTL-613R-V-TR
SW6: RIGHT; LTL-613R-V-TR
SW7: SW_SPST; SW_SPDT
U1, U2, U10, U11, U12, U13, U14, U15: SN74CBT3244; SOIC-20W_7.5x12.8mm_P1.27mm
U3: ATSAMD21J18A-AUT; TQFP-64_10x10mm_P0.5mm
U4: IR RECV; Vishay_MINICAST-3Pin
U5: 74HC14; SOIC-14_3.9x8.7mm_P1.27mm
U6: NCP1117ST33T3G; SOT-223
U7: THS7374; TSSOP-14_4.4x5mm_P0.65mm
U8: NCP1117ST50T3G; SOT-223
U9: 24LC64; MSOP-8_3x3mm_P0.65mm
U16, U18: TS5A3159DCK; SOT-363_SC-70-6
U17: LM1881; SOIC-8_3.9x4.9mm_P1.27mm
Y1: 32.768kHz; Crystal_SMD_MicroCrystal_CC8V-T1A-2Pin_2.0x1.2mm

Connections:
+3V3: C8.1, C9.1, C10.1, C12.1, C13.2, C14.1, C15.1, C25.1, C47.2, C59.2, C60.2, D5.2, FB1.2, J6.4, J10.1, J11.1, J11.4, Q3.1, Q4.1, Q5.1, Q7.1, Q8.1, Q9.1, Q10.1, Q11.1, Q12.1, Q13.1, R5.2, R6.2, R12.2, R13.2, R14.2, R15.1, R17.2, R19.1, R20.1, R23.1, R25.1, R26.1, R32.1, R54.2, R55.2, R56.2, R57.2, R58.2, R59.2, R78.2, R83.2, R84.2, R85.2, R86.2, R87.2, R88.2, U3.21, U3.34, U3.48, U3.56, U4.3, U5.14, U6.2, U6.4, U9.8
+5V: C1.2, C2.2, C23.1, C31.2, C48.2, C49.2, C50.2, C51.2, C52.2, C53.2, C56.2, C57.2, C58.2, D7.2, J20.1, Q2.3, R1.1, R2.1, R3.1, R4.1, R7.2, R8.2, R11.2, R30.1, R31.2, R33.2, R38.1, R39.1, R40.1, R41.1, R50.2, R51.2, R52.2, R53.2, R60.1, R61.1, R62.1, R63.1, R64.1, R65.1, R66.1, R67.1, R68.1, R69.1, R70.1, R71.1, R74.1, R77.2, U1.20, U2.20, U7.10, U8.2, U8.4, U10.20, U11.20, U12.20, U13.20, U14.20, U15.20, U16.5, U17.8, U18.5
+7.5V: C5.1, C21.1, C24.1, D5.1, D6.1, D7.1, Q6.2, U6.3, U8.3
/Audio Amplifier/AUDIO_AMP1: D32.1, D40.1, J5.3, J12.3, J14.3, J20.8, U1.3, U2.3, U10.3, U11.3, U12.3, U13.3, U14.3, U15.3
/Audio Amplifier/AUDIO_AMP2: D33.1, D41.1, J5.1, J12.2, J14.1, J20.7, U1.2, U2.2, U10.2, U11.2, U12.2, U13.2, U14.2, U15.2
/MCU/BTN_A: U3.41, U5.2
/MCU/BTN_D: U3.37, U5.6
/MCU/BTN_L: U3.42, U5.10
/MCU/BTN_R: U3.43, U5.8
/MCU/BTN_U: U3.38, U5.4
/MCU/BYPASS: Q5.2, R14.1, U3.31
/MCU/EXT_CTRL1: J20.3, R79.2, U3.3
/MCU/EXT_CTRL2: J20.4, R80.2, U3.4
/MCU/EXT_CTRL3: J20.5, R81.2, U3.5
/MCU/EXT_CTRL4: J20.6, R82.2, U3.6
/MCU/I2C_SCL: J11.2, R5.1, U3.36, U9.6
/MCU/I2C_SDA: J11.3, R6.1, U3.35, U9.5
/MCU/IR_RECV: U3.51, U4.1
/MCU/LCD_BL: R9.2, U3.50
/MCU/SD_MISO: J6.7, R83.1, U3.62
/MCU/SD_MOSI: J6.3, R85.1, U3.59
/MCU/SD_SCK: J6.5, R84.1, U3.60
/MCU/SWCLK: J10.4, R17.1, U3.57
/MCU/SWDIO: J10.2, U3.58
/MCU/SYNC_SPLIT: Q13.2, R78.1, U3.32
/MCU/VIDEO_CTRL1: Q5.3, R11.1, U7.9
/MCU/VIDEO_CTRL2: Q13.3, R77.1, U16.6, U18.6
/MCU/XIN32: C3.2, U3.1, Y1.1
/MCU/XOUT32: C4.2, U3.2, Y1.2
/MCU/~BUS_EN1: Q3.2, R12.1, U3.9
/MCU/~BUS_EN2: Q4.2, R13.1, U3.10
/MCU/~BUS_EN3: Q7.2, R54.1, U3.11
/MCU/~BUS_EN4: Q8.2, R55.1, U3.12
/MCU/~BUS_EN5: Q9.2, R56.1, U3.13
/MCU/~BUS_EN6: Q10.2, R57.1, U3.14
/MCU/~BUS_EN7: Q11.2, R58.1, U3.15
/MCU/~BUS_EN8: Q12.2, R59.1, U3.16
/MCU/~BUS_ENABLE1: D1.1, D2.1, Q3.3, R7.1, U1.1, U1.19
/MCU/~BUS_ENABLE2: D3.1, D4.1, Q4.3, R8.1, U2.1, U2.19
/MCU/~BUS_ENABLE3: D52.1, D53.1, Q7.3, R31.1, U10.1, U10.19
/MCU/~BUS_ENABLE4: D62.1, D63.1, Q8.3, R33.1, U11.1, U11.19
/MCU/~BUS_ENABLE5: D72.1, D73.1, Q9.3, R50.1, U12.1, U12.19
/MCU/~BUS_ENABLE6: D82.1, D83.1, Q10.3, R51.1, U13.1, U13.19
/MCU/~BUS_ENABLE7: D92.1, D93.1, Q11.3, R52.1, U14.1, U14.19
/MCU/~BUS_ENABLE8: D102.1, D103.1, Q12.3, R53.1, U15.1, U15.19
/MCU/~RESET: C14.2, R15.2, R16.2, R18.1, U3.52
/MCU/~SD_CS: J6.2, R86.1, U3.61
/SCART Input 1/AL1: D11.1, J1.6, U1.17
/SCART Input 1/AR1: D10.1, J1.2, U1.18
/SCART Input 1/BLANK1: D16.1, J1.16, JP2.1
/SCART Input 1/BLUE1: D12.1, J1.7, U1.16
/SCART Input 1/CSYNC1: D17.1, J1.20, U1.11
/SCART Input 1/FUNC1: D13.1, J1.8, JP1.1
/SCART Input 1/GREEN1: D14.1, J1.11, U1.14
/SCART Input 1/RED1: D15.1, J1.15, U1.13
/SCART Input 1/SCART1_OUT8: D30.1, D38.1, J5.8, J14.8, J20.14, U1.5, U2.5, U10.5, U11.5, U12.5, U13.5, U14.5, U15.5
/SCART Input 1/SCART16: D27.1, D35.1, J5.16, J14.16, J20.13, U1.8, U2.8, U10.8, U11.8, U12.8, U13.8, U14.8, U15.8
/SCART Input 1/VIDEO_AMP1: C27.2, J20.9, R34.1, U1.4, U2.4, U10.4, U11.4, U12.4, U13.4, U14.4, U15.4
/SCART Input 1/VIDEO_AMP2: C28.2, J20.10, R35.1, U1.6, U2.6, U10.6, U11.6, U12.6, U13.6, U14.6, U15.6
/SCART Input 1/VIDEO_AMP3: C29.2, J20.11, R36.1, U1.7, U2.7, U10.7, U11.7, U12.7, U13.7, U14.7, U15.7
/SCART Input 1/VIDEO_AMP4: J20.12, U1.9, U2.9, U10.9, U11.9, U12.9, U13.9, U14.9, U15.9, U16.4
/SCART Input 2/AL2: D19.1, J3.6, U2.17
/SCART Input 2/AR2: D18.1, J3.2, U2.18
/SCART Input 2/BLANK2: D24.1, J3.16, JP4.1
/SCART Input 2/BLUE2: D20.1, J3.7, U2.16
/SCART Input 2/CSYNC2: D25.1, J3.20, U2.11
/SCART Input 2/FUNC2: D21.1, J3.8, JP3.1
/SCART Input 2/GREEN2: D22.1, J3.11, U2.14
/SCART Input 2/RED2: D23.1, J3.15, U2.13
/SCART Input 3/AL3: D45.1, J2.6, U10.17
/SCART Input 3/AR3: D44.1, J2.2, U10.18
/SCART Input 3/BLANK3: D50.1, J2.16, JP6.1
/SCART Input 3/BLUE3: D46.1, J2.7, U10.16
/SCART Input 3/CSYNC3: D51.1, J2.20, U10.11
/SCART Input 3/FUNC3: D47.1, J2.8, JP5.1
/SCART Input 3/GREEN3: D48.1, J2.11, U10.14
/SCART Input 3/RED3: D49.1, J2.15, U10.13
/SCART Input 4/AL4: D55.1, J4.6, U11.17
/SCART Input 4/AR4: D54.1, J4.2, U11.18
/SCART Input 4/BLANK4: D60.1, J4.16, JP8.1
/SCART Input 4/BLUE4: D56.1, J4.7, U11.16
/SCART Input 4/CSYNC4: D61.1, J4.20, U11.11
/SCART Input 4/FUNC4: D57.1, J4.8, JP7.1
/SCART Input 4/GREEN4: D58.1, J4.11, U11.14
/SCART Input 4/RED4: D59.1, J4.15, U11.13
/SCART Input 5/AL5: D65.1, J7.6, U12.17
/SCART Input 5/AR5: D64.1, J7.2, U12.18
/SCART Input 5/BLANK5: D70.1, J7.16, JP10.1
/SCART Input 5/BLUE5: D66.1, J7.7, U12.16
/SCART Input 5/CSYNC5: D71.1, J7.20, U12.11
/SCART Input 5/FUNC5: D67.1, J7.8, JP9.1
/SCART Input 5/GREEN5: D68.1, J7.11, U12.14
/SCART Input 5/RED5: D69.1, J7.15, U12.13
/SCART Input 6/AL6: D75.1, J8.6, U13.17
/SCART Input 6/AR6: D74.1, J8.2, U13.18
/SCART Input 6/BLANK6: D80.1, J8.16, JP12.1
/SCART Input 6/BLUE6: D76.1, J8.7, U13.16
/SCART Input 6/CSYNC6: D81.1, J8.20, U13.11
/SCART Input 6/FUNC6: D77.1, J8.8, JP11.1
/SCART Input 6/GREEN6: D78.1, J8.11, U13.14
/SCART Input 6/RED6: D79.1, J8.15, U13.13
/SCART Input 7/AL7: D85.1, J9.6, U14.17
/SCART Input 7/AR7: D84.1, J9.2, U14.18
/SCART Input 7/BLANK7: D90.1, J9.16, JP14.1
/SCART Input 7/BLUE7: D86.1, J9.7, U14.16
/SCART Input 7/CSYNC7: D91.1, J9.20, U14.11
/SCART Input 7/FUNC7: D87.1, J9.8, JP13.1
/SCART Input 7/GREEN7: D88.1, J9.11, U14.14
/SCART Input 7/RED7: D89.1, J9.15, U14.13
/SCART Input 8/AL8: D95.1, J15.6, U15.17
/SCART Input 8/AR8: D94.1, J15.2, U15.18
/SCART Input 8/BLANK8: D100.1, J15.16, JP16.1
/SCART Input 8/BLUE8: D96.1, J15.7, U15.16
/SCART Input 8/CSYNC8: D101.1, J15.20, U15.11
/SCART Input 8/FUNC8: D97.1, J15.8, JP15.1
/SCART Input 8/GREEN8: D98.1, J15.11, U15.14
/SCART Input 8/RED8: D99.1, J15.15, U15.13
/SCART Output 1/SCART1_OUT7: C38.2, C45.1, D31.1, J5.7
/SCART Output 1/SCART1_OUT11: C36.2, C43.1, D29.1, J5.11
/SCART Output 1/SCART1_OUT15: C34.2, C41.1, D28.1, J5.15
/SCART Output 1/SCART1_OUT19: C26.1, C32.2, D26.1, J5.19
/SCART Output 2/SCART2_OUT7: C39.2, C46.1, D39.1, J14.7
/SCART Output 2/SCART2_OUT11: C37.2, C44.1, D37.1, J14.11
/SCART Output 2/SCART2_OUT15: C35.2, C42.1, D36.1, J14.15
/SCART Output 2/SCART2_OUT19: C33.2, C40.1, D34.1, J14.19
/Video Amplifier/VID_I: C54.2, R73.1, U16.1
/Video Amplifier/VID_O: R76.2, U18.1
GND: C1.1, C2.1, C3.1, C4.1, C5.2, C6.1, C7.1, C8.2, C9.2, C10.2, C11.1, C12.2, C13.1, C15.2, C16.2, C17.2, C18.2, C19.2, C20.2, C21.2, C22.2, C23.2, C24.2, C25.2, C31.1, C47.1, C48.1, C49.1, C50.1, C51.1, C52.1, C53.1, C55.1, C56.1, C57.1, C58.1, C59.1, C60.1, D8.1, D9.1, D10.2, D11.2, D12.2, D13.2, D14.2, D15.2, D16.2, D17.2, D18.2, D19.2, D20.2, D21.2, D22.2, D23.2, D24.2, D25.2, D26.2, D27.2, D28.2, D29.2, D30.2, D31.2, D32.2, D33.2, D34.2, D35.2, D36.2, D37.2, D38.2, D39.2, D40.2, D41.2, D44.2, D45.2, D46.2, D47.2, D48.2, D49.2, D50.2, D51.2, D54.2, D55.2, D56.2, D57.2, D58.2, D59.2, D60.2, D61.2, D64.2, D65.2, D66.2, D67.2, D68.2, D69.2, D70.2, D71.2, D74.2, D75.2, D76.2, D77.2, D78.2, D79.2, D80.2, D81.2, D84.2, D85.2, D86.2, D87.2, D88.2, D89.2, D90.2, D91.2, D94.2, D95.2, D96.2, D97.2, D98.2, D99.2, D100.2, D101.2, H1.1, H2.1, H3.1, H4.1, H5.1, H6.1, J1.4, J1.5, J1.9, J1.13, J1.17, J1.18, J1.21, J2.4, J2.5, J2.9, J2.13, J2.17, J2.18, J2.21, J3.4, J3.5, J3.9, J3.13, J3.17, J3.18, J3.21, J4.4, J4.5, J4.9, J4.13, J4.17, J4.18, J4.21, J5.4, J5.5, J5.9, J5.13, J5.17, J5.18, J5.21, J6.6, J7.4, J7.5, J7.9, J7.13, J7.17, J7.18, J7.21, J8.4, J8.5, J8.9, J8.13, J8.17, J8.18, J8.21, J9.4, J9.5, J9.9, J9.13, J9.17, J9.18, J9.21, J10.3, J10.5, J10.9, J11.6, J12.1, J13.2, J13.3, J14.4, J14.5, J14.9, J14.13, J14.17, J14.18, J14.21, J15.4, J15.5, J15.9, J15.13, J15.17, J15.18, J15.21, J20.2, JP1.3, JP2.3, JP3.3, JP4.3, JP5.3, JP6.3, JP7.3, JP8.3, JP9.3, JP10.3, JP11.3, JP12.3, JP13.3, JP14.3, JP15.3, JP16.3, Q1.3, R29.2, R34.2, R35.2, R36.2, R37.2, R72.1, R73.2, R75.2, R79.1, R80.1, R81.1, R82.1, SW1.2, SW2.1, SW3.1, SW4.1, SW5.1, SW6.1, U1.10, U2.10, U3.7, U3.22, U3.33, U3.47, U3.54, U4.2, U5.7, U6.1, U7.5, U7.6, U8.1, U9.1, U9.2, U9.3, U9.4, U9.7, U10.10, U11.10, U12.10, U13.10, U14.10, U15.10, U16.2, U17.4, U18.2
unnamed: C6.2, C7.2, FB1.1, U3.8
unnamed: C11.2, U3.55
unnamed: C16.1, R21.1, U5.3
unnamed: C17.1, R22.1, U5.11
unnamed: C18.1, R24.1, U5.1
unnamed: C19.1, R27.1, U5.5
unnamed: C20.1, R28.1, U5.9
unnamed: C22.1, D6.2, Q6.1, R29.1
unnamed: C26.2, C32.1, R42.1
unnamed: C27.1, R38.2, U7.1
unnamed: C28.1, R39.2, U7.2
unnamed: C29.1, R40.2, U7.3
unnamed: C30.1, R41.2, U7.4
unnamed: C30.2, R37.1, U18.4
unnamed: C33.1, C40.2, R43.1
unnamed: C34.1, C41.2, R44.1
unnamed: C35.1, C42.2, R45.1
unnamed: C36.1, C43.2, R46.1
unnamed: C37.1, C44.2, R47.1
unnamed: C38.1, C45.2, R48.1
unnamed: C39.1, C46.2, R49.1
unnamed: C54.1, R74.2, U17.2
unnamed: C55.2, R75.1, U17.6
unnamed: D1.2, R1.2
unnamed: D2.2, R2.2
unnamed: D3.2, R3.2
unnamed: D4.2, R4.2
unnamed: D8.2, R32.2
unnamed: D9.2, R30.2
unnamed: D52.2, R60.2
unnamed: D53.2, R61.2
unnamed: D62.2, R62.2
unnamed: D63.2, R63.2
unnamed: D72.2, R64.2
unnamed: D73.2, R65.2
unnamed: D82.2, R66.2
unnamed: D83.2, R67.2
unnamed: D92.2, R68.2
unnamed: D93.2, R69.2
unnamed: D102.2, R70.2
unnamed: D103.2, R71.2
unnamed: F1.1, SW7.2
unnamed: F1.2, Q6.3
unnamed: J6.1, R88.1
unnamed: J6.8, R87.1
unnamed: J10.10, R18.2
unnamed: J11.5, Q2.2
unnamed: J13.1, SW7.1
unnamed: JP1.2, U1.15
unnamed: JP2.2, U1.12
unnamed: JP3.2, U2.15
unnamed: JP4.2, U2.12
unnamed: JP5.2, U10.15
unnamed: JP6.2, U10.12
unnamed: JP7.2, U11.15
unnamed: JP8.2, U11.12
unnamed: JP9.2, U12.15
unnamed: JP10.2, U12.12
unnamed: JP11.2, U13.15
unnamed: JP12.2, U13.12
unnamed: JP13.2, U14.15
unnamed: JP14.2, U14.12
unnamed: JP15.2, U15.15
unnamed: JP16.2, U15.12
unnamed: Q1.1, R9.1, R72.2
unnamed: Q1.2, R10.2
unnamed: Q2.1, R10.1
unnamed: R16.1, SW1.1
unnamed: R19.2, R21.2, SW2.2
unnamed: R20.2, R22.2, SW3.2
unnamed: R23.2, R24.2, SW4.2
unnamed: R25.2, R27.2, SW5.2
unnamed: R26.2, R28.2, SW6.2
unnamed: R42.2, R43.2, U7.11
unnamed: R44.2, R45.2, U7.12
unnamed: R46.2, R47.2, U7.13
unnamed: R48.2, R49.2, U7.14
unnamed: R76.1, U17.1
unnamed: U16.3, U18.3

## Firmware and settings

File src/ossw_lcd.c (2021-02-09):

/* ********************************************************************** */
/*                                                                        */
/* Copyright (c) 2019-2021 Binary Solo                                    */
/*                                                                        */
/* This file is part of the Open SCART Switch project (OSSW).             */
/*                                                                        */
/* This program is free software: you can redistribute it and/or modify   */
/* it under the terms of the GNU General Public License as published by   */
/* the Free Software Foundation, either version 3 of the License, or      */
/* (at your option) any later version.                                    */
/*                                                                        */
/* This program is distributed in the hope that it will be useful,        */
/* but WITHOUT ANY WARRANTY; without even the implied warranty of         */
/* MERCHANTABILITY or FITNESS FOR A PARTICULAR PURPOSE.  See the          */
/* GNU General Public License for more details.                           */
/*                                                                        */
/* You should have received a copy of the GNU General Public License      */
/* along with this program.  If not, see <https://www.gnu.org/licenses/>  */
/*                                                                        */
/* ********************************************************************** */

/*
 * includes
 *
 */

#include <samd21.h>
#include <stdint.h>

#include <ossw_i2c.h>
#include <ossw_delay.h>

/* implements */
#include <ossw_lcd.h>

/*
 * defines
 *
 */

static const uint8_t LCD_I2C_ADDR = 0x3c;

#define LCD_CMD_FUNCTION_SET1   (uint8_t) 0x38
#define LCD_CMD_FUNCTION_SET2   (uint8_t) 0x39
#define LCD_CMD_SET_BIAS        (uint8_t) 0x14
#define LCD_CMD_SET_CONTRAST    (uint8_t) 0x78
#define LCD_CMD_POWER_CTRL      (uint8_t) 0x5E
#define LCD_CMD_FOLLOW_CTRL     (uint8_t) 0x6C
#define LCD_CMD_DISPLAY_ON      (uint8_t) 0x0C
#define LCD_CMD_DISPLAY_OFF     (uint8_t) 0x08
#define LCD_CMD_CLEAR_DISPLAY   (uint8_t) 0x01
#define LCD_CMD_RETURN_HOME     (uint8_t) 0x02
#define LCD_CMD_SET_ENTRY_MODE  (uint8_t) 0x06
#define LCD_CMD_SET_DDRAM_ADDR  (uint8_t) 0x80
#define LCD_CMD_SET_CGRAM_ADDR  (uint8_t) 0x40

#define LCD_CTRL_BYTE           (uint8_t) 0x0

#define LCD_CTRL_BYTE_REPEAT    (1 << 7)
#define LCD_CTRL_BYTE_REGSEL    (1 << 6)
#define LCD_CTRL_BYTE_FOLLOW    (1 << 7)

#define LCD_WRITE_FUNCTION_SET1 lcd_write_instruction(LCD_CMD_FUNCTION_SET1)
#define LCD_WRITE_FUNCTION_SET2 lcd_write_instruction(LCD_CMD_FUNCTION_SET2)
#define LCD_WRITE_SET_BIAS      lcd_write_instruction(LCD_CMD_SET_BIAS)
#define LCD_WRITE_SET_CONTRAST  lcd_write_instruction(LCD_CMD_SET_CONTRAST)
#define LCD_WRITE_POWER_CTRL    lcd_write_instruction(LCD_CMD_POWER_CTRL)
#define LCD_WRITE_FOLLOW_CTRL   lcd_write_instruction(LCD_CMD_FOLLOW_CTRL)
#define LCD_WRITE_DISPLAY_ON    lcd_write_instruction(LCD_CMD_DISPLAY_ON)
#define LCD_WRITE_DISPLAY_OFF   lcd_write_instruction(LCD_CMD_DISPLAY_OFF)
#define LCD_WRITE_CLEAR_DISPLAY lcd_write_instruction(LCD_CMD_CLEAR_DISPLAY)
#define LCD_WRITE_ENTRY_MODE    lcd_write_instruction(LCD_CMD_SET_ENTRY_MODE)
#define LCD_WRITE_RETURN_HOME   lcd_write_instruction(LCD_CMD_RETURN_HOME)

#define LCD_CGRAM_ADDR_SHIFT    3

#define LCD_SET_DDRAM_ADDR(a) \
    lcd_write_instruction(LCD_CMD_SET_DDRAM_ADDR | a)

#define LCD_SET_CGRAM_ADDR(num) \
    lcd_write_instruction(LCD_CMD_SET_CGRAM_ADDR | (num << LCD_CGRAM_ADDR_SHIFT))

#define LCD_WRITE_DATA(c)       lcd_write_data(c)

#define LCD_MEM_ROW1_MIN        0x00
#define LCD_MEM_ROW1_MAX        0x27
#define LCD_MEM_ROW2_MIN        0x40
#define LCD_MEM_ROW2_MAX        0x67

#define LCD_SET_CONTRAST(c) \
    lcd_write_instruction(((LCD_CMD_SET_CONTRAST & 0xF0) | (c & 0x0F)))

#define LCD_DELAY               30

#define LCD_I2C_BUFFER_LEN      (size_t) 2

/* LCD backlight */

#define LCD_BL_PORT             0x01        /* Port Group B */

#define PORT_LCD_BL             PORT_PB23
#define PIN_LCD_BL              PIN_PB23

/*
 * globals
 *
 */

/**
 * LCD contrast
 */
static uint8_t g_lcd_contrast = 0;

/*
 * static functions
 *
 */

static void 
lcd_write_instruction(uint8_t cmd)
{
    uint8_t buf[LCD_I2C_BUFFER_LEN] = { 0 };

    buf[0] = LCD_CTRL_BYTE;
    buf[1] = cmd;

    ossw_i2c_write(LCD_I2C_ADDR, buf, LCD_I2C_BUFFER_LEN);
    delay_us(LCD_DELAY);
}

static void
lcd_write_data(uint8_t data)
{
    uint8_t buf[LCD_I2C_BUFFER_LEN] = { 0 };

    buf[0] = LCD_CTRL_BYTE | LCD_CTRL_BYTE_REGSEL;
    buf[1] = data;

    ossw_i2c_write(LCD_I2C_ADDR, buf, LCD_I2C_BUFFER_LEN);
    delay_us(LCD_DELAY);
}

void 
ossw_lcd_init(void)
{
    /* init backlight */
    PORT->Group[LCD_BL_PORT].DIRSET.reg = PORT_LCD_BL;
    ossw_lcd_backlight_enable();

    /* init display */
    delay_ms(500);

    LCD_WRITE_FUNCTION_SET1;

    LCD_WRITE_FUNCTION_SET2;

    LCD_WRITE_SET_BIAS;

    LCD_WRITE_SET_CONTRAST;
    g_lcd_contrast = LCD_CMD_SET_CONTRAST & 0x0F;

    LCD_WRITE_POWER_CTRL;

    LCD_WRITE_FOLLOW_CTRL;

    LCD_WRITE_DISPLAY_ON;

    LCD_WRITE_CLEAR_DISPLAY;
    delay_ms(2);

    LCD_WRITE_ENTRY_MODE;
}

void
ossw_lcd_clear_display(void)
{
    LCD_WRITE_CLEAR_DISPLAY;
    delay_ms(2);
}

void
ossw_lcd_return_home(void)
{
    LCD_WRITE_RETURN_HOME;
    delay_ms(2);
}

void
ossw_lcd_set_contrast(uint8_t val)
{
    if(val > OSSW_LCD_CONTRAST_MAX) {
        return;
    }

    /* 
     * contrast allowable range is 4-bit 
     * value so discard upper 4 bits of val 
     */
    if((val & 0x0F) != g_lcd_contrast) {
        LCD_SET_CONTRAST(val);
        g_lcd_contrast = val & 0x0F;
    }
}

void
ossw_lcd_set_cursor(uint8_t row, uint8_t col)
{
    uint8_t addr = 0;

    if((row < 1) || (row > OSSW_LCD_ROW_NUM) || \
            (col < 1) || (col > OSSW_LCD_COL_NUM)) {
        return;
    }

    addr = (((row == OSSW_LCD_ROW_NUM) ? LCD_MEM_ROW2_MIN : LCD_MEM_ROW1_MIN) | (col - 1)); 

    LCD_SET_DDRAM_ADDR(addr);
}

void
ossw_lcd_print_char(char c)
{
    LCD_WRITE_DATA(c);
}

void
ossw_lcd_print_string(char* s)
{
    char* p = NULL;

    if(NULL == s) {
        return;
    }
    p = s;

    while(*p) ossw_lcd_print_char(*(p++));
}

void
ossw_lcd_display(char* s1, char* s2, uint8_t j1, uint8_t j2)
{
    if((NULL == s1) || (NULL == s2) || (j1 > 2) || (j2 > 2)) {
        return;
    }

    ossw_lcd_clear_display();
    ossw_lcd_return_home();

    ossw_lcd_set_cursor(1,1);
    ossw_lcd_print_string(s1);

    ossw_lcd_set_cursor(2,1);
    ossw_lcd_print_string(s2);
}
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

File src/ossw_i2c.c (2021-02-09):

/* ********************************************************************** */
/*                                                                        */
/* Copyright (c) 2019-2021 Binary Solo                                    */
/*                                                                        */
/* This file is part of the Open SCART Switch project (OSSW).             */
/*                                                                        */
/* This program is free software: you can redistribute it and/or modify   */
/* it under the terms of the GNU General Public License as published by   */
/* the Free Software Foundation, either version 3 of the License, or      */
/* (at your option) any later version.                                    */
/*                                                                        */
/* This program is distributed in the hope that it will be useful,        */
/* but WITHOUT ANY WARRANTY; without even the implied warranty of         */
/* MERCHANTABILITY or FITNESS FOR A PARTICULAR PURPOSE.  See the          */
/* GNU General Public License for more details.                           */
/*                                                                        */
/* You should have received a copy of the GNU General Public License      */
/* along with this program.  If not, see <https://www.gnu.org/licenses/>  */
/*                                                                        */
/* ********************************************************************** */

/*
 * includes
 *
 */

#include <samd21.h>
#include <string.h>

/* implements */
#include <ossw_i2c.h>

/*
 * defines
 *
 */

#define PORT_WRCONFIG_PERIPHERAL_FUNCTION_C 0x02

#define I2C_CONTROL (1 << 7)
#define I2C_REGSEL  (1 << 6)

#define BUF_NUM     0x2

#define BUF_TX      0x0
#define BUF_RX      0x1

#define BUF_DONE    0x1

enum i2c_mode {
    I2C_MODE_READ,
    I2C_MODE_WRITE
};

static volatile struct i2c_data {

    uint8_t* buf;
    uint8_t  done;

    size_t   len;
    size_t   idx;

} i2c_buf[BUF_NUM];

static inline void
sercom_i2c_peripheral_init(void)
{
    /*
     * Enable SERCOM1 peripheral in
     * Power Manager
     */
    PM->APBCMASK.reg |= PM_APBCMASK_SERCOM1;
}

static inline void
sercom_i2c_clock_init(void)
{
    /* 
     * Configure SERCOM1_CORE with source of 
     * Generic Clock Generator 0 and enable 
     */
    GCLK->CLKCTRL.reg = GCLK_CLKCTRL_ID(SERCOM1_GCLK_ID_CORE) |
      GCLK_CLKCTRL_CLKEN | GCLK_CLKCTRL_GEN(0);
 
    /* 
     * Configure SERCOM1_SLOW with source of 
     * Generic Clock Generator 0 and enable 
     */
    GCLK->CLKCTRL.reg = GCLK_CLKCTRL_ID(SERCOM1_GCLK_ID_SLOW) |
      GCLK_CLKCTRL_CLKEN | GCLK_CLKCTRL_GEN(0);
}

static inline void
sercom_i2c_pin_init(void)
{
    PORT->Group[0].WRCONFIG.reg = 
        PORT_WRCONFIG_HWSEL | 
        PORT_WRCONFIG_WRPINCFG | 
        PORT_WRCONFIG_WRPMUX | 
        PORT_WRCONFIG_PMUX(PORT_WRCONFIG_PERIPHERAL_FUNCTION_C) | 
        PORT_WRCONFIG_PMUXEN | 
        PORT_WRCONFIG_PINMASK((PORT_PA16C_SERCOM1_PAD0 >> 16) | (PORT_PA17C_SERCOM1_PAD1 >> 16));
}

static inline void
sercom_i2c_master_init(void)
{
    /* 
     * Configure SERCOM1 as I2C.
     *
     * NOTE: SERCOM_I2CM_CTRLA_SPEED = FAST_MODE (400KHz, default register = 0) so
     * no need to set this. SDA_HOLD 300-600ns, MODE I2C Master.
     */
    SERCOM1->I2CM.CTRLA.reg = SERCOM_I2CM_CTRLA_SDAHOLD(0x2) |
        SERCOM_I2CM_CTRLA_RUNSTDBY | SERCOM_I2CM_CTRLA_MODE_I2C_MASTER;

    /* enable smart mode */
    SERCOM1->I2CM.CTRLB.reg = SERCOM_I2CM_CTRLB_SMEN;

    /* sync busy */
    while(SERCOM1->I2CM.SYNCBUSY.bit.SYSOP);

    /* BAUDLOW is non-zero, and baud register is loaded */
    SERCOM1->I2CM.BAUD.reg = SERCOM_I2CM_BAUD_BAUD(220);

    /* sync busy */
    while(SERCOM1->I2CM.SYNCBUSY.bit.SYSOP);

    /* enable SERCOM1 peripheral by setting ENABLE to 1 */
    SERCOM1->I2CM.CTRLA.reg |= SERCOM_I2CM_CTRLA_ENABLE;

    /* SERCOM ENABLE sync busy */
    while((SERCOM1->I2CM.SYNCBUSY.reg & SERCOM_I2CM_SYNCBUSY_ENABLE));

    /* force bus into idle state */
    SERCOM1->I2CM.STATUS.bit.BUSSTATE = 0x1;

    /* sync busy */
    while(SERCOM1->I2CM.SYNCBUSY.bit.SYSOP);

    /* set interrupts bit, both master on bus and slave on bus enabled */
    SERCOM1->I2CM.INTENSET.reg = SERCOM_I2CM_INTENSET_MB | SERCOM_I2CM_INTENSET_SB;

    /* enable SERCOM1 interrupt handler */
	NVIC_EnableIRQ(SERCOM1_IRQn);
}

static void
sercom_i2c_transact(uint8_t addr, int mode)
{
    /* acknowledge is set as ACK signal by writing 0 in ACKACT bit */
    SERCOM1->I2CM.CTRLB.reg &= ~SERCOM_I2CM_CTRLB_ACKACT;
    while(SERCOM1->I2CM.SYNCBUSY.bit.SYSOP);

    if(I2C_MODE_WRITE == mode) {

        /* slave address with Write(0) */
        SERCOM1->I2CM.ADDR.reg = (addr << 1) | 0;

        while(!i2c_buf[BUF_TX].done);
    }

    if(I2C_MODE_READ == mode) {

        /* slave address with Read(1) */
        SERCOM1->I2CM.ADDR.reg = (addr << 1) | 1;

        while(!i2c_buf[BUF_RX].done);
    }
}

/*
 * I2C interrupt handler
 */
void
SERCOM1_Handler(void)
{
    /* Master on bus */
    if(SERCOM1->I2CM.INTFLAG.bit.MB){

        if(i2c_buf[BUF_TX].idx == i2c_buf[BUF_TX].len){

            /* after last byte send stop condition */
            SERCOM1->I2CM.CTRLB.bit.CMD = 0x3;
            while(SERCOM1->I2CM.SYNCBUSY.bit.SYSOP);

            i2c_buf[BUF_TX].done = BUF_DONE;

        } else {

            if(i2c_buf[BUF_TX].buf != NULL){

                /* send data and increment tx buffer */
                SERCOM1->I2CM.DATA.reg = i2c_buf[BUF_TX].buf[i2c_buf[BUF_TX].idx];
                i2c_buf[BUF_TX].idx++;

                while(SERCOM1->I2CM.SYNCBUSY.bit.SYSOP);
            }
        }
    }

    /* Slave on bus */
    if(SERCOM1->I2CM.INTFLAG.bit.SB){

        if(i2c_buf[BUF_RX].buf != NULL){

            if (i2c_buf[BUF_RX].idx == (i2c_buf[BUF_RX].len - 1)) {

                /* send NACK after reading last byte */
                SERCOM1->I2CM.CTRLB.reg |= SERCOM_I2CM_CTRLB_ACKACT;
                while(SERCOM1->I2CM.SYNCBUSY.bit.SYSOP);

                SERCOM1->I2CM.CTRLB.bit.CMD = 0x3;
                while(SERCOM1->I2CM.SYNCBUSY.bit.SYSOP);

                i2c_buf[BUF_RX].buf[i2c_buf[BUF_RX].idx] = SERCOM1->I2CM.DATA.reg;
                while(SERCOM1->I2CM.SYNCBUSY.bit.SYSOP);

                i2c_buf[BUF_RX].done = BUF_DONE;

            } else {

                SERCOM1->I2CM.CTRLB.reg &= ~SERCOM_I2CM_CTRLB_ACKACT;
                while(SERCOM1->I2CM.SYNCBUSY.bit.SYSOP);

                i2c_buf[BUF_RX].buf[i2c_buf[BUF_RX].idx] = SERCOM1->I2CM.DATA.reg;
                i2c_buf[BUF_RX].idx++;
                while(SERCOM1->I2CM.SYNCBUSY.bit.SYSOP);

                /* sending ACK after reading each byte */
                SERCOM1->I2CM.CTRLB.bit.CMD = 0x2;
                while(SERCOM1->I2CM.SYNCBUSY.bit.SYSOP);
            }
        }
    }
}
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
